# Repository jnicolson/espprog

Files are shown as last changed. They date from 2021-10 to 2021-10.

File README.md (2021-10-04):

# ESP32 Programmer

This is a USB-C programmer for ESP32 chips, including autoreset as documented by espressif.  The pinout is compatible with the ESPFlash convention proposed by SuperHouse at https://www.superhouse.tv/espflash/ .

Additionally, 5V is exposed from the USB port (after the protection fuse) - this allows the ESP programmer to be used as a USB to serial module providing both 5V and 3.3V.  The 5V can either be connected via a jumper wire (if the programmer is mounted vertically) or directly via a pin (if mounted horizontally)

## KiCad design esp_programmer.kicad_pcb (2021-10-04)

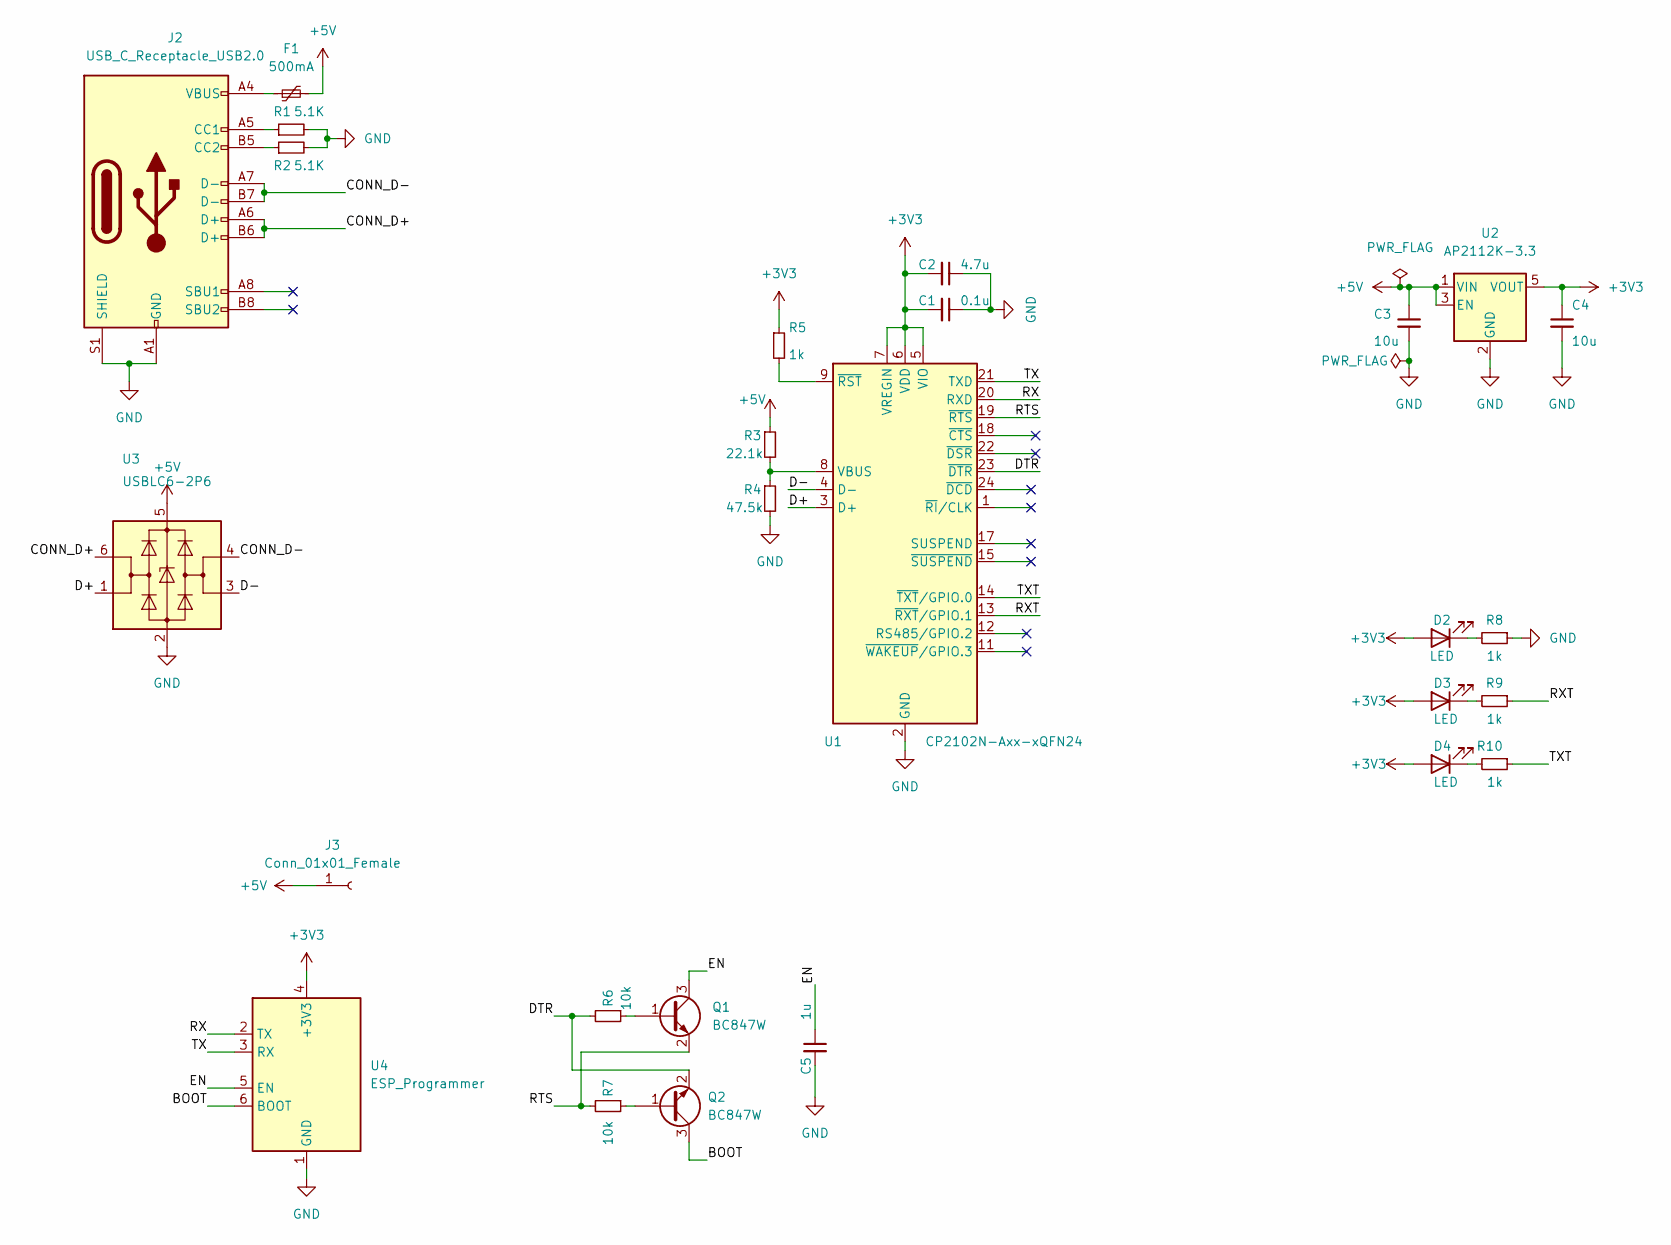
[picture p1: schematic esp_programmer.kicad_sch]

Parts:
C1: 0.1u; C_0603_1608Metric
C2: 4.7u; C_0603_1608Metric
C3, C4: 10u; C_0603_1608Metric
C5: 1u; C_0603_1608Metric
D2, D3, D4: LED; LED_0603_1608Metric
F1: 500mA; Fuse_1206_3216Metric
J2: USB_C_Receptacle_USB2.0; USB_C_Receptacle_HRO_TYPE-C-31-M-12
J3: Conn_01x01_Female; PinSocket_1x01_P2.54mm_Vertical
Q1, Q2: BC847W; SOT-323_SC-70
R1, R2: 5.1K; R_0603_1608Metric
R3: 22.1k; R_0603_1608Metric
R4: 47.5k; R_0603_1608Metric
R5, R8, R9, R10: 1k; R_0603_1608Metric
R6, R7: 10k; R_0603_1608Metric
U1: CP2102N-Axx-xQFN24; QFN-24-1EP_4x4mm_P0.5mm_EP2.6x2.6mm
U2: AP2112K-3.3; SOT-23-5
U3: USBLC6-2P6; SOT-666
U4: ESP_Programmer; PinHeader_1x06_P2.54mm_Vertical

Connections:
+3V3: C1.2, C2.2, C4.1, D2.2 (A), D3.2 (A), D4.2 (A), R5.1, U1.5 (VIO), U1.6 (VDD), U1.7 (VREGIN), U2.5 (VOUT), U4.4 (+3V3)
+5V: C3.1, F1.2, J3.1, R3.1, U2.1 (VIN), U2.3 (EN), U3.5 (VBUS)
/BOOT: Q2.3 (C), U4.6 (BOOT)
/CONN_D+: J2.A6 (D+), J2.B6 (D+), U3.6 (I/O1)
/CONN_D-: J2.A7 (D-), J2.B7 (D-), U3.4 (I/O2)
/D+: U1.3 (D+), U3.1 (I/O1)
/D-: U1.4 (D-), U3.3 (I/O2)
/DTR: Q2.2 (E), R6.2, U1.23 (~DTR)
/EN: C5.1, Q1.3 (C), U4.5 (EN)
/RTS: Q1.2 (E), R7.2, U1.19 (~RTS)
/RX: U1.20 (RXD), U4.2 (TX)
/RXT: R9.1, U1.13 (~RXT/GPIO.1)
/TX: U1.21 (TXD), U4.3 (RX)
/TXT: R10.1, U1.14 (~TXT/GPIO.0)
GND: C1.1, C2.1, C3.2, C4.2, C5.2, J2.A1 (GND), J2.A12 (GND), J2.B1 (GND), J2.B12 (GND), J2.S1 (SHIELD), R1.2, R2.2, R4.2, R8.1, U1.2 (GND), U1.25 (GND), U2.2 (GND), U3.2 (GND), U4.1 (GND)
unnamed: D2.1 (K), R8.2
unnamed: D3.1 (K), R9.2
unnamed: D4.1 (K), R10.2
unnamed: F1.1, J2.A4 (VBUS), J2.A9 (VBUS), J2.B4 (VBUS), J2.B9 (VBUS)
unnamed: J2.A5 (CC1), R1.1
unnamed: J2.B5 (CC2), R2.1
unnamed: Q1.1 (B), R6.1
unnamed: Q2.1 (B), R7.1
unnamed: R3.2, R4.1, U1.8 (VBUS)
unnamed: R5.2, U1.9 (~RST)

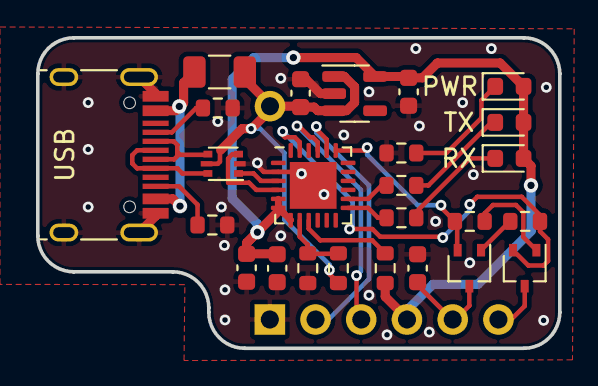
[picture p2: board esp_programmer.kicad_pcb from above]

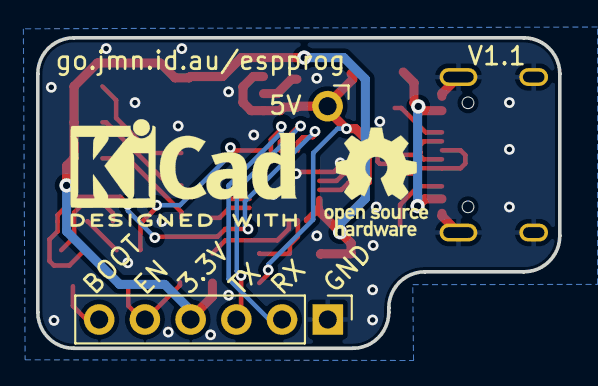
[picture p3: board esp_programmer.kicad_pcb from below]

Board: 2 copper layers, 29.0 x 17.2 mm, 27 parts (2 on the bottom side), 25 nets.
